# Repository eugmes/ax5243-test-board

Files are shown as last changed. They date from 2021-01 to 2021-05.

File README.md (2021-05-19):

AX5243 Shield for Arduino Nano (3.3V)
=====================================

This is a small test board for AX5243 narrow-band transceiver chip with pinout
compatible with Arduino Nano. Note that the board requires 3.3V supply voltage.

The antenna is matched at 169 MHz. The board is designed using
[KiCad](https://kicad.org), and currently requires a nightly build
(version 5.99). The [schematic](schematic/ax5243-test-board.pdf) is also
available in PDF format. The generated gerber files are available in
[gerbers](gerbers) directory. The board is also available on
[Aisler](https://aisler.net/p/OMGYYSHU) (latest available revision is
[B](https://github.com/eugmes/ax5243-test-board/releases/tag/rev-B)).

The produced board was tested using NUCLEO-L432KC development board
and was able to receive and transmit AIS signals. Some test software is
available here: https://github.com/eugmes/ax5243-zephyr

Changes since last release:

* Added additional matching capacitor that is needed for higher frequencies.

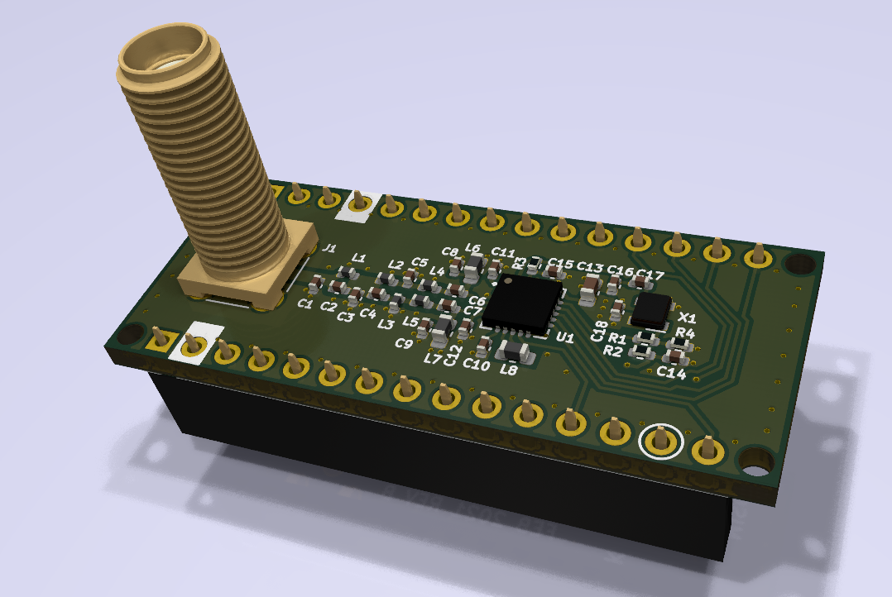
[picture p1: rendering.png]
Board rendering


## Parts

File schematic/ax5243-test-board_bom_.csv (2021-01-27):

References | Value | Footprint | Quantity Per PCB | MFT Name | MFT Number | Vendor | SKU | Config | Rating
C14 | 100nF | C_0402_1005Metric | 1 | Murata | GRM155R71H104KE14D | Digikey | 490-10700-1-ND
C11 C12 | 100pF | C_0402_1005Metric | 2 | Murata | GCM1555C1H101GA16D | Digikey | 490-GCM1555C1H101GA16DCT-ND
C18 | 10nF | C_0402_1005Metric | 1 | Murata | GRM155R71H103KA88J | Digikey | 490-6351-1-ND
C6 C7 C8 C9 | 10pF | C_0402_1005Metric | 4 | Murata | GJM1555C1H100FB01D | Digikey | 490-11189-1-ND
C4 C5 | 12pF | C_0402_1005Metric | 2 | Murata | GJM1555C1H120JB01D | Digikey | 490-3115-1-ND
C15 C17 | 1nF | C_0402_1005Metric | 2 | Murata | GRM1555C1H102GA01D | Digikey | 490-8181-1-ND
C1 C3 | 27pF | C_0402_1005Metric | 2 | Murata | GJM1555C1H270FB01D | Digikey | 490-16380-1-ND
C10 | 39pF | C_0402_1005Metric | 1 | Murata | GJM1555C1H390JB01D | Digikey | 490-17673-1-ND
C13 | 4.7uF | C_0603_1608Metric | 1 | Murata | GRM188R61E475KE11D | Digikey | 490-7203-1-ND
C2 | 6.8pF | C_0402_1005Metric | 1 | Murata | GJM1555C1H6R8CB01D | Digikey | 490-3106-1-ND
J1 | CONSMA008-G | SMA_Amphenol_132291-12_Vertical | 1 | Linx Technologies | CONSMA008-G | Digikey | CONSMA008-G-ND
J2 J3 | Conn_01x15 | PinSocket_1x15_P2.54mm_Vertical | 2 | Harwin | M20-7821546 | Digikey | 952-2290-ND
L4 L5 | 120nH | L_0402_1005Metric | 2 | Murata | LQW15ANR12J00D | Digikey | 490-4091-1-ND
L6 L7 | 150nH | L_0603_1608Metric | 2 | Murata | LQW18ANR15J00D | Digikey | 490-6924-1-ND
L1 | 33nH | L_0402_1005Metric | 1 | Murata | LQW15AN33NH00D | Digikey | 490-6805-1-ND
L2 L3 | 68nH | L_0402_1005Metric | 2 | Murata | LQW15AN68NG00D | Digikey | 490-6837-1-ND
L8 | 68nH | L_0603_1608Metric | 1 | Murata | LQW18AN68NG00D | Digikey | 490-6904-1-ND |  | wirewound
R2 | 100 | R_0402_1005Metric | 1 | Yageo | RC0402FR-07100RP | Digikey | YAG1248CT-ND
R3 | 1k | R_0402_1005Metric | 1 | Yageo | RC0402FR-071KP | Digikey | YAG1254CT-ND
U1 | AX5243 | QFN50P400X400X80-21B-THERMALVIAS | 1 | ON Semiconductor | AX5243-1-TW30 | Digikey | 488-AX5243-1-TW30CT-ND
X1 | 26MHz | Oscillator_SMD_Abracon_ASDMB-4Pin_2.5x2.0mm | 1 | Taitien | TYETACSANF-26.000000 | Digikey | 1664-1297-1-ND |  | 0.5ppm

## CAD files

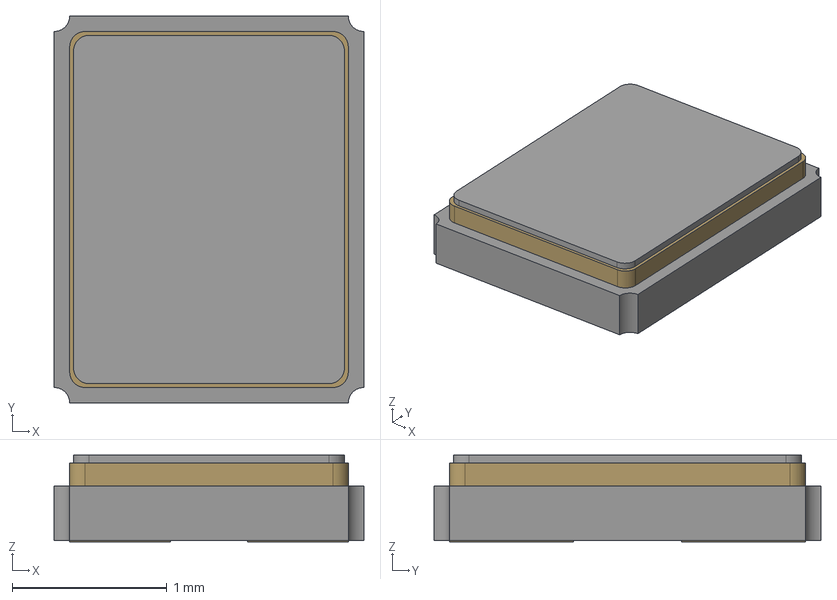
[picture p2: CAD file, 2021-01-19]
crystal.step
2.00 x 2.50 x 0.56 mm

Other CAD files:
crystal.FCStd

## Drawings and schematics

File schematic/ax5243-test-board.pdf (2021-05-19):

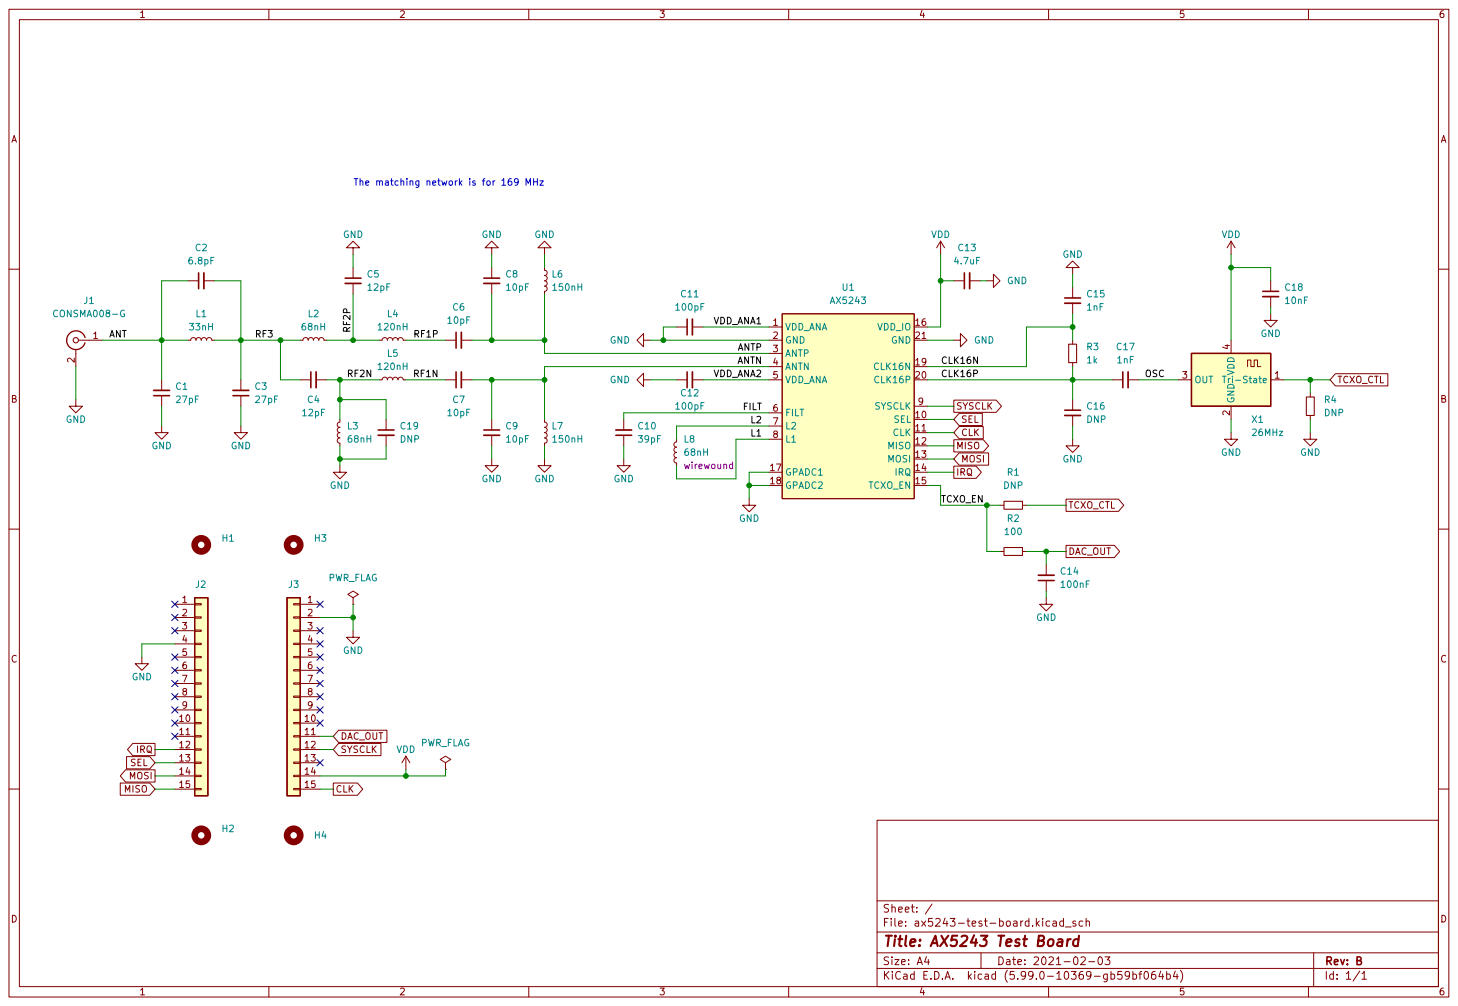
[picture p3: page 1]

File: ax5243-test-board.kicad_sch Sheet: /
Id: 1/1 Title: AX5243 Test Board

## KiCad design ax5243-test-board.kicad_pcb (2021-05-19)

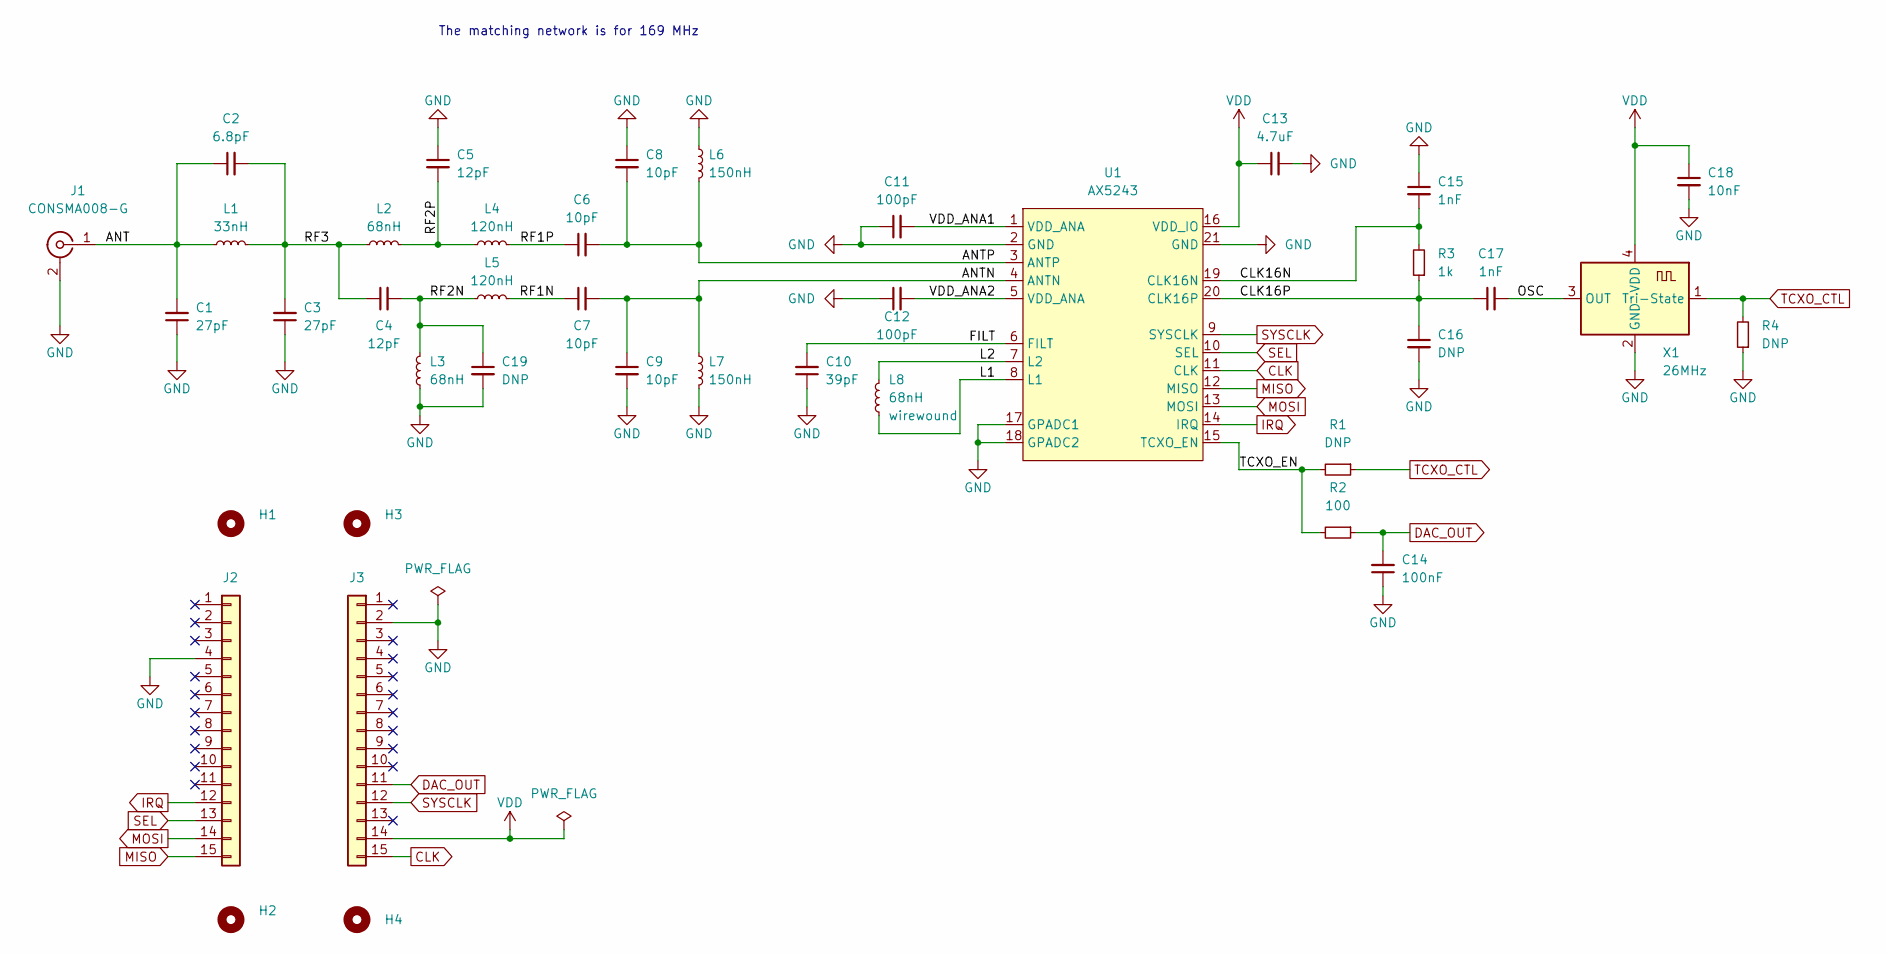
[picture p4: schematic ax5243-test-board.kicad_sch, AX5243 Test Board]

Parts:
C1, C3: 27pF; C_0402_1005Metric
C2: 6.8pF; C_0402_1005Metric
C4, C5: 12pF; C_0402_1005Metric
C6, C7, C8, C9: 10pF; C_0402_1005Metric
C10: 39pF; C_0402_1005Metric
C11, C12: 100pF; C_0402_1005Metric
C13: 4.7uF; C_0603_1608Metric
C14: 100nF; C_0402_1005Metric
C15, C17: 1nF; C_0402_1005Metric
C16, C19: DNP; C_0402_1005Metric
C18: 10nF; C_0402_1005Metric
H1, H2, H3, H4: MountingHole; MountingHole_1.8mm
J1: CONSMA008-G; SMA_Amphenol_132291-12_Vertical
J2, J3: Conn_01x15; PinSocket_1x15_P2.54mm_Vertical
L1: 33nH; L_0402_1005Metric
L2, L3: 68nH; L_0402_1005Metric
L4, L5: 120nH; L_0402_1005Metric
L6, L7: 150nH; L_0603_1608Metric
L8: 68nH; L_0603_1608Metric; Rating wirewound
R1, R4: DNP; R_0402_1005Metric
R2: 100; R_0402_1005Metric
R3: 1k; R_0402_1005Metric
U1: AX5243; QFN50P400X400X80-21B-THERMALVIAS
X1: 26MHz; Oscillator_SMD_Abracon_ASDMB-4Pin_2.5x2.0mm

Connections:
/ANT: C1.2, C2.1, J1.1 (In), L1.1
/ANTN: C7.2, C9.1, L7.1, U1.4 (ANTN)
/ANTP: C6.2, C8.2, L6.2, U1.3 (ANTP)
/CLK16N: C15.2, R3.2, U1.19 (CLK16N)
/CLK16P: C16.1, C17.1, R3.1, U1.20 (CLK16P)
/FILT: C10.2, U1.6 (FILT)
/L1: L8.1, U1.8 (L1)
/L2: L8.2, U1.7 (L2)
/OSC: C17.2, X1.3 (OUT)
/RF1N: C7.1, L5.2
/RF1P: C6.1, L4.2
/RF2N: C4.2, C19.1, L3.2, L5.1
/RF2P: C5.2, L2.2, L4.1
/RF3: C2.2, C3.2, C4.1, L1.2, L2.1
/TCXO_EN: R1.2, R2.2, U1.15 (TCXO_EN)
/VDD_ANA1: C11.2, U1.1 (VDD_ANA)
/VDD_ANA2: C12.2, U1.5 (VDD_ANA)
CLK: J3.15, U1.11 (CLK)
DAC_OUT: C14.2, J3.11, R2.1
GND: C1.1, C3.1, C5.1, C8.1, C9.2, C10.1, C11.1, C12.1, C13.2, C14.1, C15.1, C16.2, C18.2, C19.2, J1.2 (Ext), J2.4, J3.2, L3.1, L6.1, L7.2, R4.1, U1.2 (GND), U1.17 (GPADC1), U1.18 (GPADC2), U1.21 (GND), X1.2 (GND)
IRQ: J2.12, U1.14 (IRQ)
MISO: J2.15, U1.12 (MISO)
MOSI: J2.14, U1.13 (MOSI)
SEL: J2.13, U1.10 (SEL)
SYSCLK: J3.12, U1.9 (SYSCLK)
TCXO_CTL: R1.1, R4.2, X1.1 (Tri-State)
VDD: C13.1, C18.1, J3.14, U1.16 (VDD_IO), X1.4 (VDD)

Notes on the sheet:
The matching network is for 169 MHz

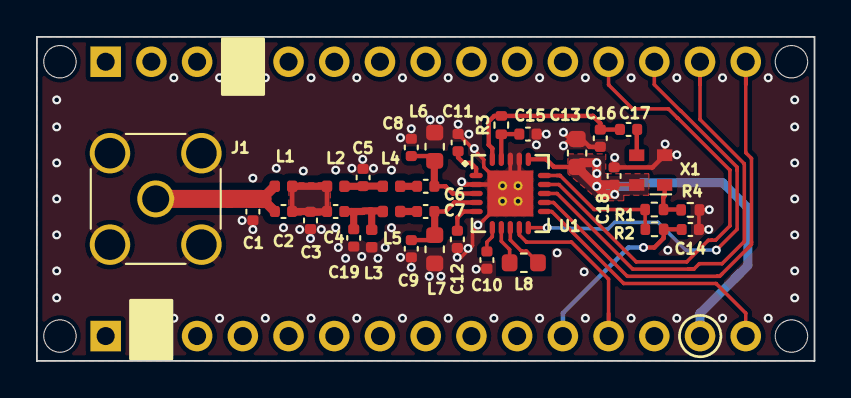
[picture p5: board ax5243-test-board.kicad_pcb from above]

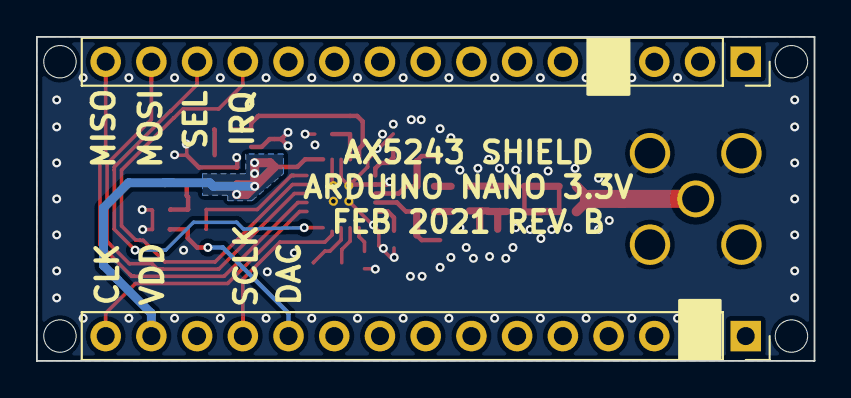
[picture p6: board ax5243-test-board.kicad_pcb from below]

Board: 2 copper layers, 43.2 x 18.0 mm, 40 parts (2 on the bottom side), 27 nets.

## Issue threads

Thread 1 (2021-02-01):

Wrong distance between pin headers

eugmes, 2021-02-01:
The distance between Arduino Nano headers is 500 mil instead of 600 mil.

eugmes, 2021-02-02:
The layout was fixed in da24a35721c20a7a9923973d08efb6b907c25f7b.

eugmes, 2021-02-15:
Fixed in 7c6d1a647a40e7df5a0e8956b6cad28b76cbed5d

Closed 2021-02-15.

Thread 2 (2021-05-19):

Pick and Place data is missing in gerber

KenLagoni, 2021-05-19:
I would like to try this PCB, but the pick and place data is not included.

eugmes, 2021-05-19:
@KenLagoni I've added a component placement file generated by KiCad, but please note that I was assembling those boards manually, so this file is unverified.

eugmes, 2021-05-19:
Hmm, I've generated this file with wrong options, and the transceiver chip is missing there.

Closed 2021-05-19.

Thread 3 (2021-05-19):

No footprint for capacitor CM2

KenLagoni, 2021-05-19:
This capacitor is not mounted when frequency is 169MHz, but If one wish to use this PCB with other frequency’s then capacitor CM2 (from datasheet page 33) is missing.

eugmes, 2021-05-19:
I guess I can add that capacitor, but I was making this board to see if ax5243 can be used to receive AIS signal, and given that it works for me now, I don't expect to be making new versions of this board any time soon.

KenLagoni, 2021-05-19:
Nice that you managed to get it working as AIS receiver, I'm trying to build an EPIRB detector using this PCB.

eugmes, 2021-05-19:
I've added the capacitor now and regenerated gerbers/placement/schematic files. This passes DRC, but otherwise untested. Also, I'll be very interested to know how your project goes.

Closed 2021-05-19.

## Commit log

2021-01-19 Add gerbers for ordered board
    [ax5243-test-board-B_Cu.gbl, ax5243-test-board-B_Mask.gbs, ax5243-test-board-B_Silkscreen.gbo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]
2021-01-19 Add schematic plot
2021-01-22 Add .gitignore and remove kicad_prl file from the repo
2021-01-27 Add part numbers and Digikey SKUs
    Also change TCXO frequency to 26 MHz.
    [ax5243-test-board.kicad_pcb, ax5243-test-board.kicad_sch]
2021-01-27 Rename schematic and gerbers directories
    [ax5243-test-board-B_Cu.gbl, ax5243-test-board-B_Mask.gbs, ax5243-test-board-B_Silkscreen.gbo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]
2021-01-27 Add BOM file
    [ax5243-test-board_bom_.csv]
2021-01-27 Add board rendering
2021-01-27 Correct the link to the schematic
2021-01-27 Remove footer from the BOM file
    [ax5243-test-board_bom_.csv]
2021-02-02 Move the extension connections to the correct location
    Add solder mask extension.
    [ax5243-test-board.kicad_pcb]
2021-02-15 New kicad nigtly version
    [ax5243-test-board.kicad_pcb, ax5243-test-board.kicad_sch]
2021-02-15 Update production files
    [ax5243-test-board-B_Cu.gbl, ax5243-test-board-B_Mask.gbs, ax5243-test-board-B_Silkscreen.gbo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]
2021-05-19 Add component placement files
    This file is completely unverified. Closes: #2.
    [ax5243-test-board-all-pos.csv]
2021-05-19 Regenerate the placement file
    Don't use "Exclude all footprints with through hole pads" this time, so
    that the trnsceiver chip is not excluded. Really closes: #2.
    [ax5243-test-board-all-pos.csv]
2021-05-19 Update the README stating that the board is working
2021-05-19 Add additional matching capacitor needed for higher frequencies
    This closes: #3
    [ax5243-test-board-B_Cu.gbl, ax5243-test-board-B_Mask.gbs, ax5243-test-board-B_Silkscreen.gbo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]
